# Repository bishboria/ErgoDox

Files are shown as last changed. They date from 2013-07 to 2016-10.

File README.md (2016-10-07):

# Information

My colemak layout (without `teensy button`) http://configure.ergodox-ez.com/keyboard_layouts/qajjmk/edit 

I aim for symmetry of modifier keys, primarily: I get Emacs Pinky quite quickly when using a standard (1 ctrl button) laptop keyboard.

## Updating the keyboard layout

Use ErgoDox EZ configurator (with my layout as the basis): http://configure.ergodox-ez.com/keyboard_layouts/qajjmk/edit

This great configurator has loads of extra keys that I had to add manually, and painfully, to a `C` file.

## Updating keyboard layout

* Run teensy.app from teensy.dmg
* Press +L1 then teensy button (on the old layout, EZ layout configurator doesn't have this `teensy button`)
* Open newest .hex file
* Program
* Reboot

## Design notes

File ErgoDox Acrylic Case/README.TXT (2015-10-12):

Layer thickness:
  Layers 1,5: 3mm
  Layers 2,3,4: 4mm

  Total thickness: 18mm

Disclaimer: No guarantee or warranty implied.  Use these drawings at your own risk.

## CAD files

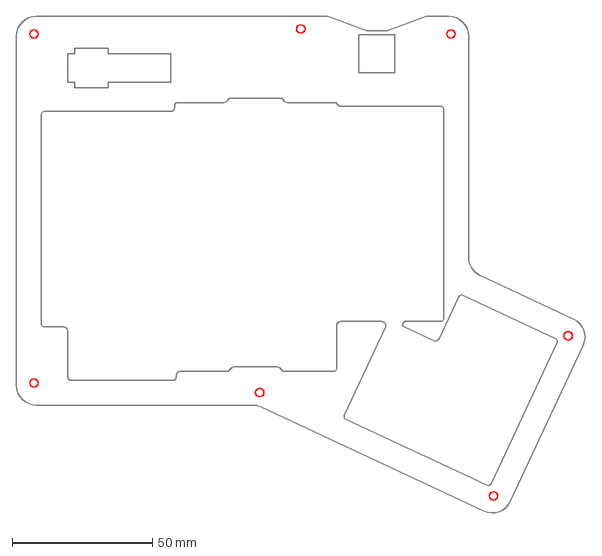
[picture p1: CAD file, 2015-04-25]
ErgoDox Acrylic Case/ErgoDOX Acrylic Case - Designed by Litster/Standard/Left/ErgoDOX Case Layer 2 Spacer - Left.dxf
202.8 x 177.8 mm

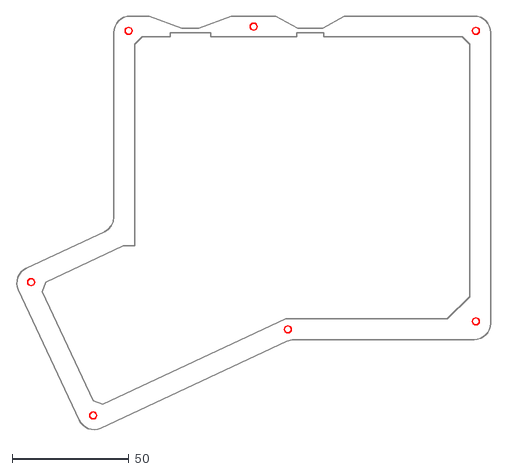
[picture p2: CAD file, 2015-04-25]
ErgoDox Acrylic Case/ErgoDOX Acrylic Case - Designed by Litster/Standard/Right/ErgoDOX Case Layer 4 Spacer - Right.dxf
202.8 x 177.8

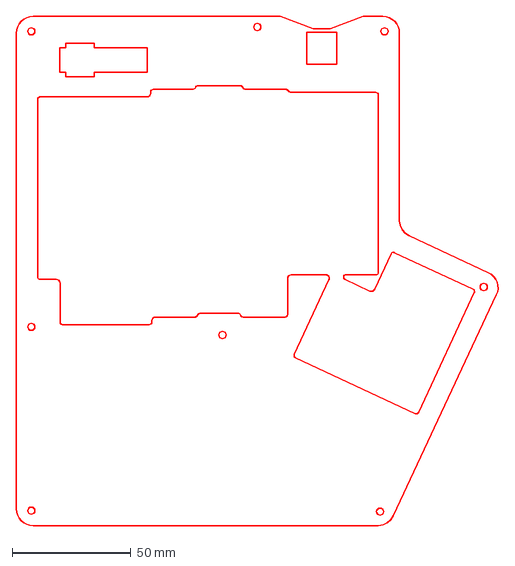
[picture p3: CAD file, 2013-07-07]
ErgoDox Acrylic Case/ErgoDOX Acrylic Case - Designed by Litster/with Wrist Rest/Left/ErgoDOX Case Layer 2 Spacer - Left.dxf
202.8 x 214.1 mm

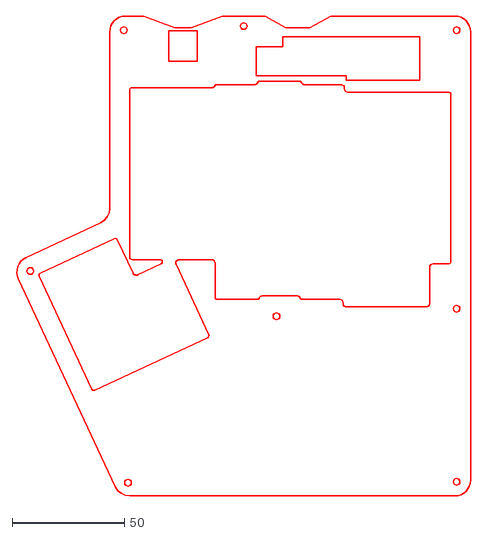
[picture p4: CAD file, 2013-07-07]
ErgoDox Acrylic Case/ErgoDOX Acrylic Case - Designed by Litster/with Wrist Rest/Right/ErgoDOX Wrist Rest Case Layer 2 Spacer - Right.dxf
202.8 x 214.1

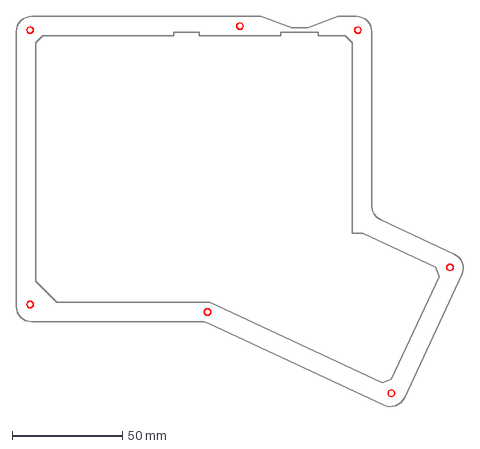
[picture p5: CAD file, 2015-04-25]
ErgoDox Acrylic Case/ErgoDOX Acrylic Case - Designed by Litster/Standard/Left/ErgoDOX Case Layer 4 Spacer - Left.dxf
202.8 x 177.8 mm

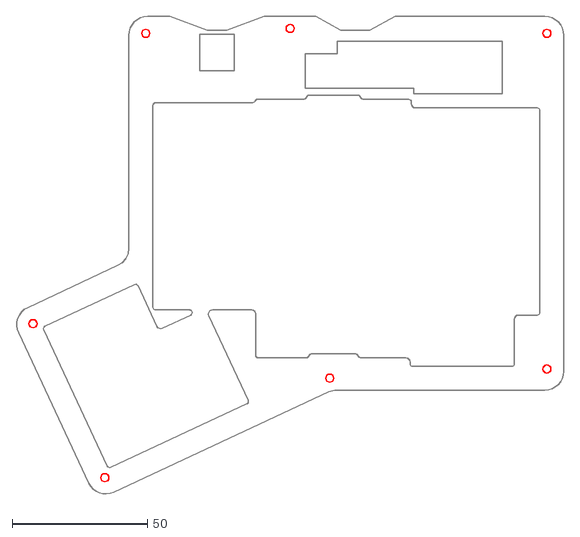
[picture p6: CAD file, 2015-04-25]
ErgoDox Acrylic Case/ErgoDOX Acrylic Case - Designed by Litster/Standard/Right/ErgoDOX Case Layer 2 Spacer - Right.dxf
202.8 x 177.8

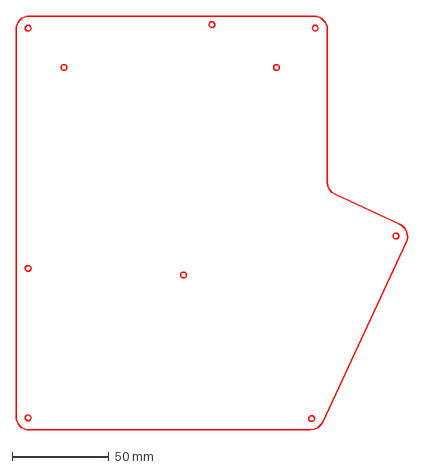
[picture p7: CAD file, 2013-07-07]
ErgoDox Acrylic Case/ErgoDOX Acrylic Case - Designed by Litster/with Wrist Rest/Left/ErgoDOX Case Layer 5 Bottom - Left.dxf
202.8 x 214.1 mm

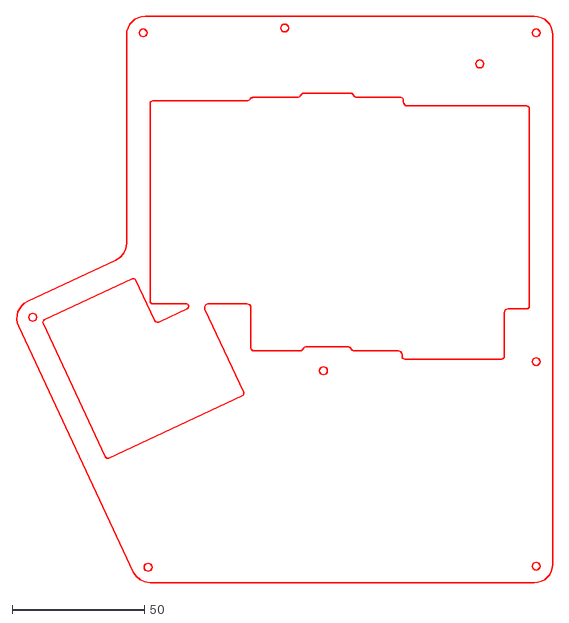
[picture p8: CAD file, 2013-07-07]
ErgoDox Acrylic Case/ErgoDOX Acrylic Case - Designed by Litster/with Wrist Rest/Right/ErgoDOX Wrist Rest Case Layer 1 Top - Right.dxf
202.8 x 214.1

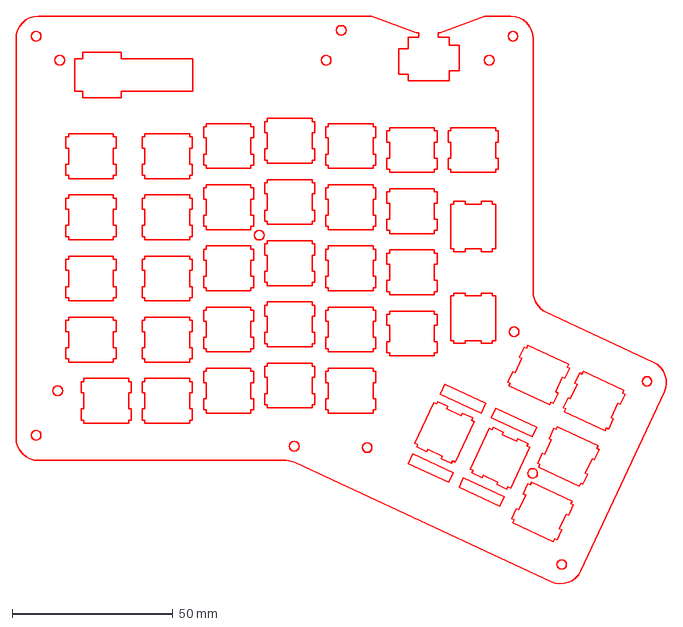
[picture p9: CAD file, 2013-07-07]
ErgoDox Acrylic Case/ErgoDOX Acrylic Case - Designed by Litster/Standard/Left/ErgoDOX Case Layer 3 Plate - Left.dxf
202.8 x 177.8 mm

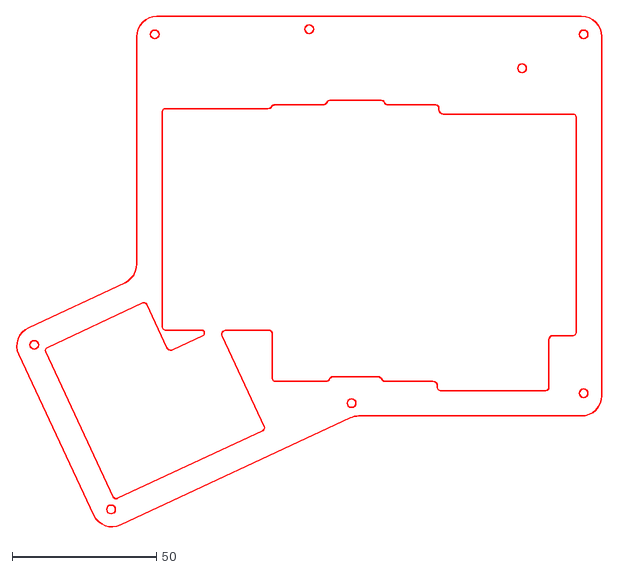
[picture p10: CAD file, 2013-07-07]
ErgoDox Acrylic Case/ErgoDOX Acrylic Case - Designed by Litster/Standard/Right/ErgoDOX Case Layer 1 Top - Right.dxf
202.8 x 177.8

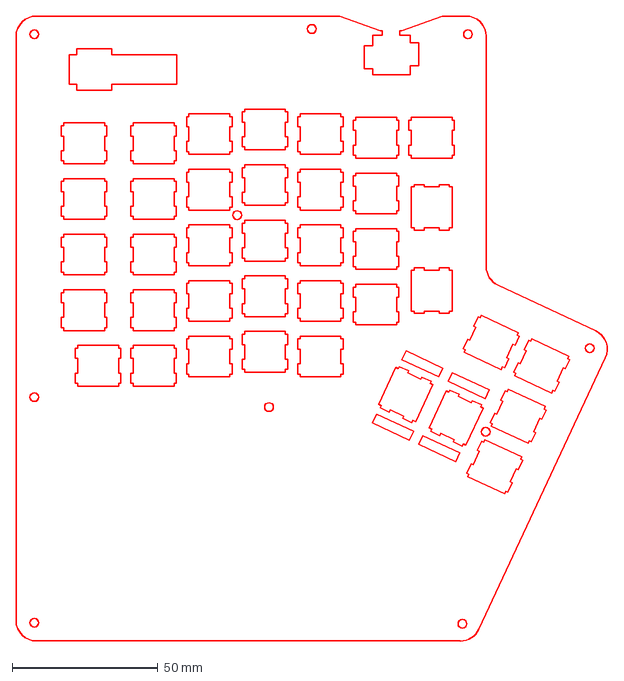
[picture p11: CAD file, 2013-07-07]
ErgoDox Acrylic Case/ErgoDOX Acrylic Case - Designed by Litster/with Wrist Rest/Left/ErgoDOX Case Layer 3 Plate - Left.dxf
202.8 x 214.1 mm

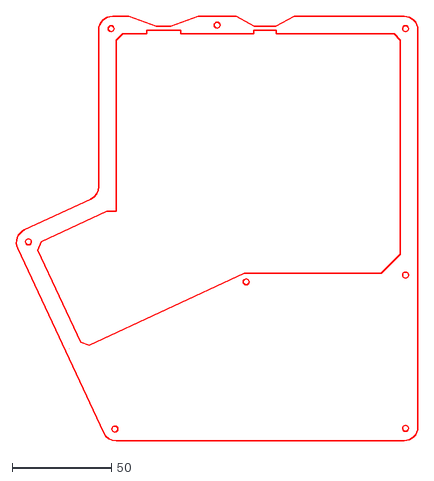
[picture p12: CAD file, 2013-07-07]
ErgoDox Acrylic Case/ErgoDOX Acrylic Case - Designed by Litster/with Wrist Rest/Right/ErgoDOX Wrist Rest Case Layer 4 Spacer - Right.dxf
202.8 x 214.1

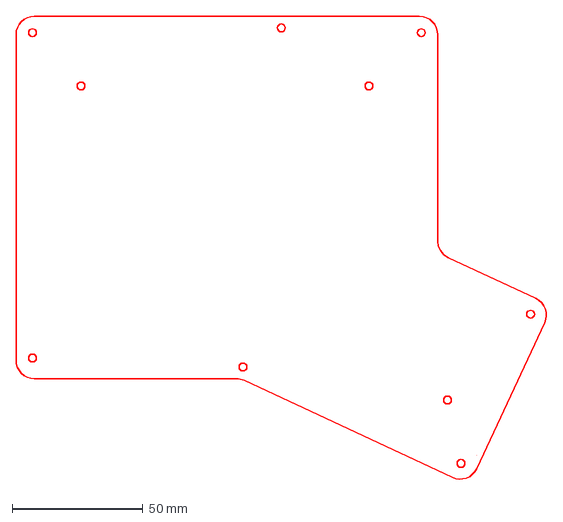
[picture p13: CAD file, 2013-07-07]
ErgoDox Acrylic Case/ErgoDOX Acrylic Case - Designed by Litster/Standard/Left/ErgoDOX Case Layer 5 Bottom - Left.dxf
202.8 x 177.8 mm

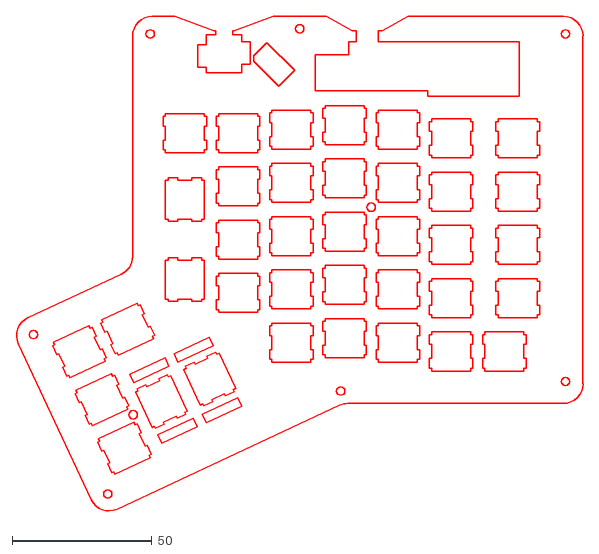
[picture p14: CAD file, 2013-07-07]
ErgoDox Acrylic Case/ErgoDOX Acrylic Case - Designed by Litster/Standard/Right/ErgoDOX Case Layer 3 Plate - Right.dxf
202.8 x 177.8

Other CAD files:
ErgoDox Acrylic Case/ErgoDOX Acrylic Case - Designed by Litster/with Wrist Rest/Left/ErgoDOX Case Layer 1 Top - Left.dxf
ErgoDox Acrylic Case/ErgoDOX Acrylic Case - Designed by Litster/with Wrist Rest/Right/ErgoDOX Wrist Rest Case Layer 3 Plate - Right.dxf
ErgoDox Acrylic Case/ErgoDOX Acrylic Case - Designed by Litster/Standard/Left/ErgoDOX Case Layer 1 Top - Left.dxf
ErgoDox Acrylic Case/ErgoDOX Acrylic Case - Designed by Litster/Standard/Right/ErgoDOX Case Layer 5 Bottom - Right.dxf
ErgoDox Acrylic Case/ErgoDOX Acrylic Case - Designed by Litster/with Wrist Rest/Left/ErgoDOX Case Layer 4 Spacer - Left.dxf
ErgoDox Acrylic Case/ErgoDOX Acrylic Case - Designed by Litster/with Wrist Rest/Left/test cut.dxf
ErgoDox Acrylic Case/ErgoDOX Acrylic Case - Designed by Litster/with Wrist Rest/Right/ErgoDOX Wrist Rest Case Layer 5 Bottom - Right.dxf

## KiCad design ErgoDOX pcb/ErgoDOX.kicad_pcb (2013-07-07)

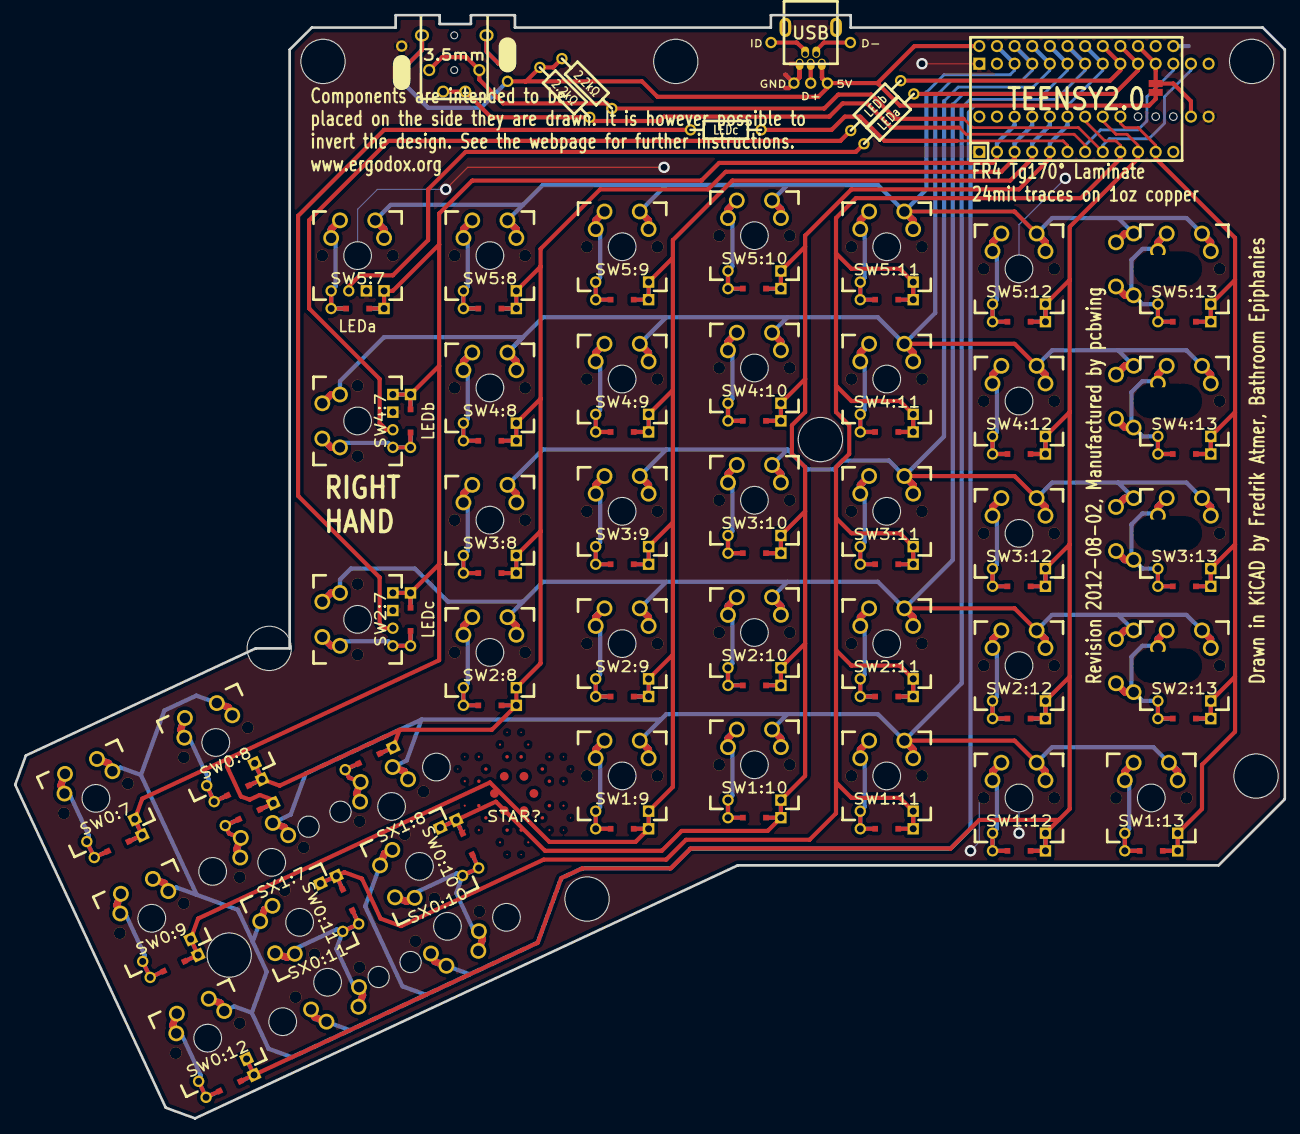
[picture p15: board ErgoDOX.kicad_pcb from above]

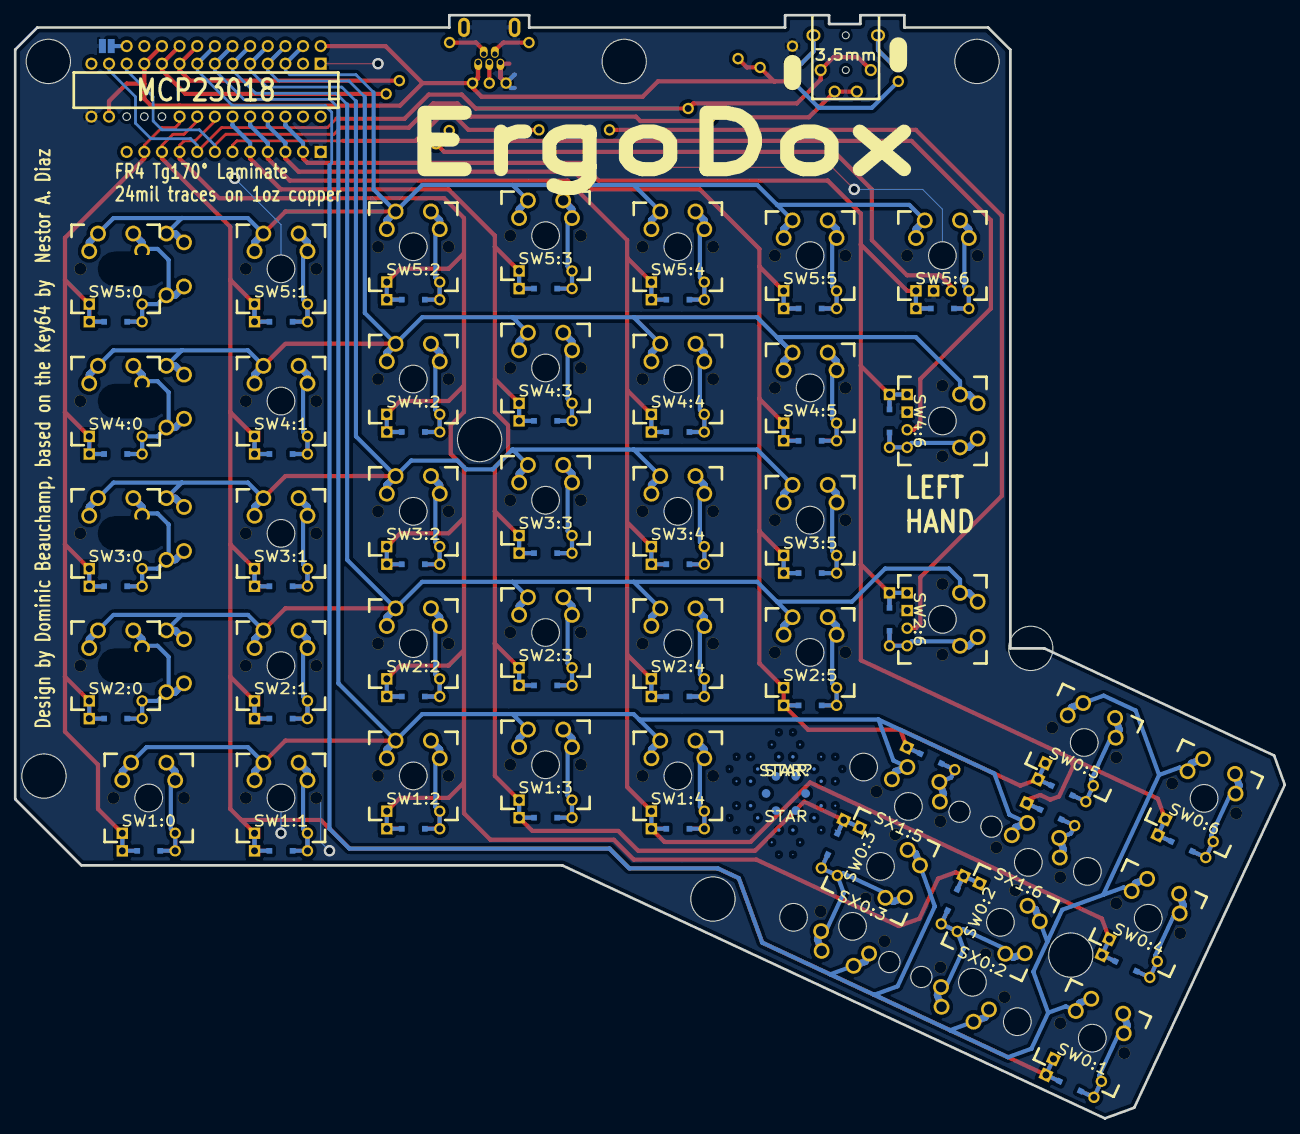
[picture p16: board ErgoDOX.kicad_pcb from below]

Board: 2 copper layers, 182.8 x 158.9 mm, 65 parts (4 on the bottom side), 65 nets.

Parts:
D1:7, D1:8: D; DIODE
H99: MECHANICAL; ErgoDOXmech
J1: USB; USBMINImod
J2: 3.5mm; 4pin35mmAudio
J3, J4: JMP; 100PITCH1X3
JP1, JP2: JUMPER; GAP
LED_A1: LEDa; MX_LED
LED_B1: LEDb; MX_LED
LED_C1: LEDc; MX_LED
R1, R2: 2.2kΩ; RESISTOR
RA1: LEDa; RESISTOR
RB1: LEDb; RESISTOR
RC1: LEDc; RESISTOR
S1, S2: STAB200; STAB_PCB940
STAR?: STAR
STAR?#2: STAR
SW0:7: SW0:6; MX_FLIP_DIODE
SW0:8: SW0:5; MX_FLIP_DIODE
SW0:9: SW0:4; MX_FLIP_DIODE
SW0:10: SW0:3; MX_FLIP_DIODE
SW0:11: SW0:2; MX_FLIP_DIODE
SW0:12: SW0:1; MX_FLIP_DIODE
SW1:9: SW1:4; MX_FLIP_DIODE
SW1:10: SW1:3; MX_FLIP_DIODE
SW1:11: SW1:2; MX_FLIP_DIODE
SW1:12: SW1:1; MX_FLIP_DIODE
SW1:13: SW1:0; MX_FLIP_DIODE
SW2:7: SW2:6; MX_FLIP_DIODE
SW2:8: SW2:5; MX_FLIP_DIODE
SW2:9: SW2:4; MX_FLIP_DIODE
SW2:10: SW2:3; MX_FLIP_DIODE
SW2:11: SW2:2; MX_FLIP_DIODE
SW2:12: SW2:1; MX_FLIP_DIODE
SW2:13: SW2:0; MX_FLIP_XX
SW3:8: SW3:5; MX_FLIP_DIODE
SW3:9: SW3:4; MX_FLIP_DIODE
SW3:10: SW3:3; MX_FLIP_DIODE
SW3:11: SW3:2; MX_FLIP_DIODE
SW3:12: SW3:1; MX_FLIP_DIODE
SW3:13: SW3:0; MX_FLIP_XX
SW4:7: SW4:6; MX_FLIP_DIODE
SW4:8: SW4:5; MX_FLIP_DIODE
SW4:9: SW4:4; MX_FLIP_DIODE
SW4:10: SW4:3; MX_FLIP_DIODE
SW4:11: SW4:2; MX_FLIP_DIODE
SW4:12: SW4:1; MX_FLIP_DIODE
SW4:13: SW4:0; MX_FLIP_XX
SW5:7: SW5:6; MX_FLIP_DIODE
SW5:8: SW5:5; MX_FLIP_DIODE
SW5:9: SW5:4; MX_FLIP_DIODE
SW5:10: SW5:3; MX_FLIP_DIODE
SW5:11: SW5:2; MX_FLIP_DIODE
SW5:12: SW5:1; MX_FLIP_DIODE
SW5:13: SW5:0; MX_FLIP_XX
SX0:10: SX0:3; MX_FLIP
SX0:11: SX0:2; MX_FLIP
SX1:7: SX1:6; MX_FLIP
SX1:8: SX1:5; MX_FLIP
U1: TEENSY2.0; TEENSY_2.0
U2: MCP23018; DIP28_300

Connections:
/COL0: SW1:13.4, SW2:13.4, SW3:13.4, SW4:13.4, SW5:13.4, U1.11, U2.20
/COL1: SW0:12.4, SW1:12.4, SW2:12.4, SW3:12.4, SW4:12.4, SW5:12.4, U1.10, U2.21
/COL4: SW0:9.4, SW1:9.4, SW2:9.4, SW3:9.4, SW4:9.4, SW5:9.4, U1.4, U2.24
/COL5: D1:8.2, SW0:8.4, SW2:8.4, SW3:8.4, SW4:8.4, SW5:8.4, U1.3, U2.25
/COL6: D1:7.2, SW0:7.4, SW2:7.4, SW4:7.4, SW5:7.4, U1.2, U2.26
/COL10: SW0:10.4, SW1:10.4, SW2:10.4, SW3:10.4, SW4:10.4, SW5:10.4, U1.5, U2.23
/COL11: SW0:11.4, SW1:11.4, SW2:11.4, SW3:11.4, SW4:11.4, SW5:11.4, U1.9, U2.22
/LED_A: RA1.1, U1.21
/LED_B: RB1.1, U1.22
/LED_C: RC1.1, U1.6
/ROW0: SW0:7.1, SW0:8.1, SW0:9.1, SW0:10.1, SW0:11.1, SW0:12.1, SX0:10.1, SX0:11.1, U1.23, U2.8
/ROW1: SW1:9.1, SW1:10.1, SW1:11.1, SW1:12.1, SW1:13.1, SX1:7.1, SX1:8.1, U1.24, U2.7
/ROW2: SW2:7.1, SW2:8.1, SW2:9.1, SW2:10.1, SW2:11.1, SW2:12.1, SW2:13.1, U1.25, U2.6
/ROW3: SW3:8.1, SW3:9.1, SW3:10.1, SW3:11.1, SW3:12.1, SW3:13.1, U1.26, U2.5
/ROW4: SW4:7.1, SW4:8.1, SW4:9.1, SW4:10.1, SW4:11.1, SW4:12.1, SW4:13.1, U1.27, U2.4
/ROW5: SW5:7.1, SW5:8.1, SW5:9.1, SW5:10.1, SW5:11.1, SW5:12.1, SW5:13.1, U1.28, U2.3
/SCLM: J2.3, J2.5, R2.2, U1.7, U2.12
/SDAM: J2.2, J2.6, R1.2, U1.8, U2.13
GND: H99.0, J1.5, J1.6, J3.3, J4.3, JP2.1, LED_A1.2, LED_B1.2, LED_C1.2, S1.0, S2.0, SW0:7.0, SW0:8.0, SW0:9.0, SW0:10.0, SW0:11.0, SW0:12.0, SW1:9.0, SW1:10.0, SW1:11.0, SW1:12.0, SW1:13.0, SW2:7.0, SW2:8.0, SW2:9.0, SW2:10.0, SW2:11.0, SW2:12.0, SW2:13.0, SW3:8.0, SW3:9.0, SW3:10.0, SW3:11.0, SW3:12.0, SW3:13.0, SW4:7.0, SW4:8.0, SW4:9.0, SW4:10.0, SW4:11.0, SW4:12.0, SW4:13.0, SW5:7.0, SW5:8.0, SW5:9.0, SW5:10.0, SW5:11.0, SW5:12.0, SW5:13.0, SX0:10.0, SX0:11.0, SX1:7.0, SX1:8.0, U1.1, U1.18, U2.1, U2.15
unnamed: J2.4, J4.2
unnamed: J2.1, J3.2
unnamed: SW5:12.2, SW5:12.3
unnamed: SW5:8.2, SW5:8.3
unnamed: SW5:7.2, SW5:7.3
unnamed: D1:8.1, SX1:8.2
unnamed: SW5:9.2, SW5:9.3
unnamed: SW5:10.2, SW5:10.3
unnamed: SW5:11.2, SW5:11.3
unnamed: SW1:9.2, SW1:9.3
unnamed: SW0:10.2, SW0:10.3, SX0:10.2
unnamed: D1:7.1, SX1:7.2
unnamed: SW2:10.2, SW2:10.3
unnamed: SW3:9.2, SW3:9.3
unnamed: SW3:8.2, SW3:8.3
unnamed: SW2:7.2, SW2:7.3
unnamed: SW2:8.2, SW2:8.3
unnamed: SW2:9.2, SW2:9.3
unnamed: SW2:11.2, SW2:11.3
unnamed: SW1:11.2, SW1:11.3
unnamed: SW1:10.2, SW1:10.3
unnamed: SW2:12.2, SW2:12.3
unnamed: SW5:13.2, SW5:13.3
unnamed: SW4:9.2, SW4:9.3
unnamed: SW4:11.2, SW4:11.3
unnamed: SW4:12.2, SW4:12.3
unnamed: SW2:13.2, SW2:13.3
unnamed: SW4:13.2, SW4:13.3
unnamed: SW3:13.2, SW3:13.3
unnamed: SW3:12.2, SW3:12.3
unnamed: SW3:11.2, SW3:11.3
unnamed: SW3:10.2, SW3:10.3
unnamed: SW0:8.2, SW0:8.3
unnamed: SW1:13.2, SW1:13.3
unnamed: SW1:12.2, SW1:12.3
unnamed: SW0:12.2, SW0:12.3
unnamed: SW0:9.2, SW0:9.3
unnamed: SW0:7.2, SW0:7.3
unnamed: SW4:7.2, SW4:7.3
unnamed: SW4:8.2, SW4:8.3
unnamed: SW4:10.2, SW4:10.3
unnamed: LED_C1.1, RC1.2
unnamed: LED_B1.1, RB1.2
unnamed: LED_A1.1, RA1.2
unnamed: SW0:11.2, SW0:11.3, SX0:11.2
VCC: J1.1, J3.1, J4.1, JP1.1, R1.1, R2.1, U1.20, U1.29, U2.11, U2.16

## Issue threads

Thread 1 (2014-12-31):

Cleanup some dxf files so they more suited for laser cutting

edkolev, 2014-12-31:
Hi, and thanks for providing these files - I used them to laser cut a case.

However, the laser-cutting-company complained that the files had some minor issues, like:
- the lines were not connected everywhere
- some line were duplicated (2 line on top of each other)
- the lines were not combined into a polyline

That's why I had to cleanup some of the files, which leads me to my question: are you interested in merging back these changes? You can see my changes here https://github.com/edkolev/ErgoDox

I haven't updated all the files because the company did that themselves, but didn't send me back the modified files.

tekamolo, 2015-03-26:
What is the program you are opening the dxf files with? I tried with Autocad 2007 and there is an error:

Invalid or incomplete DXF input -- drawing discarded.

I don't know if this is a compatible version problem or it is a corruption file problem.

bishboria, 2015-03-27:
Apologies for only just noticing this issue!

I grabbed the dxf files from another source and didn't check to see if they were valid… If you open a PR with the files updated I'd gladly merge the changes in.

edkolev, 2015-04-08:
@tekamolo, I edited the files with LibreCAD, then I sent them to a friend to check them with AutoCAD. He applied some minor changes and sent them back. I'll ask him which version of AutoCAD  he edited them with.

BTW I have no problems editing the files with LibreCAD. Maybe you're having issues due to the old AutoCAD version.

@bishboria, I'll open a PR

edkolev, 2015-04-08:
The files have been edited in autocad 2011, but have been saved for 2004

Closed 2015-04-08.

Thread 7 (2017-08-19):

the plate from case and plate builder does not align

harshitgoel96, 2017-08-19:
Hi,

I generated a plate file from plate and case builder using the KLE ergodox design. The thumb switches do not align. Can you please confirm that it will not align ?

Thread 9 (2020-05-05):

SW2:13, SW3:13, SW4:13 and SW5:13 have NPTHs that are not layered as such

sunwukonga, 2020-05-05:
On commit a2602c4 accepted on Dec 6, 2016. There are four (4) switch locations with three (3) holes each that are not properly identified as NPTH.

These are easy to change, but I don't know what settings have been used in the past to plot the Gerber files and generate drill files, so I'll leave the PR to someone who has done it on this project in the past.

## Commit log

2013-07-07 Keyboard configuration and how to update it.
    [ErgoDOX Case Layer 1 Top - Left.dxf, ErgoDOX Case Layer 1 Top - Right.dxf, ErgoDOX Case Layer 2 Spacer - Left.dxf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]
2014-12-31 Remove unnecessary space in file names
    [ErgoDOX Case Layer 4 Spacer - Left.dxf]
2014-12-31 Cleanup dxf files so they more suited for laser cutting
    These changes have been applied:
    - duplicated lines have been removed
    - random dots have been removed
    - lines have been combined into a polyline
    [ErgoDOX Case Layer 2 Spacer - Left.dxf, ErgoDOX Case Layer 2 Spacer - Right.dxf, ErgoDOX Case Layer 4 Spacer - Left.dxf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]
